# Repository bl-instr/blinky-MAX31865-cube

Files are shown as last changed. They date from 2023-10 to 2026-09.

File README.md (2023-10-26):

#    Blinky-MAX31864 Cube # 
The Blinky-MAX31865 cube is a precision 4 terminal resistance measurement device that integrates into a Blinky-Lite control platform. The cubes incorporates two [Adafruit MAX31865 breakout boards](https://www.adafruit.com/product/3648) providing two independent measurment channels with 15 bits of resolution

## Features: ##
- Seamless integration into the open source [Blinky-Lite control platform](https://www.blinky-lite.se/) 
- Wireless connection for data acquistion and control
- Web interface for wireless connection configuration
- Two independent channels
- Eighth order Chebyschev or power series temperature fit via web interface
- 100 mS pulsed measurements for low self heating
- User defined IIR filtering
- User defined measurement rate
- 15 bits of resolution

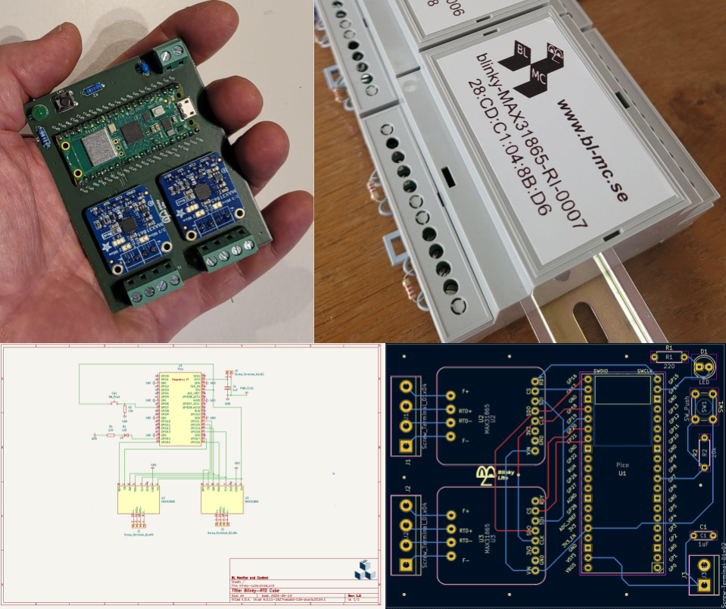
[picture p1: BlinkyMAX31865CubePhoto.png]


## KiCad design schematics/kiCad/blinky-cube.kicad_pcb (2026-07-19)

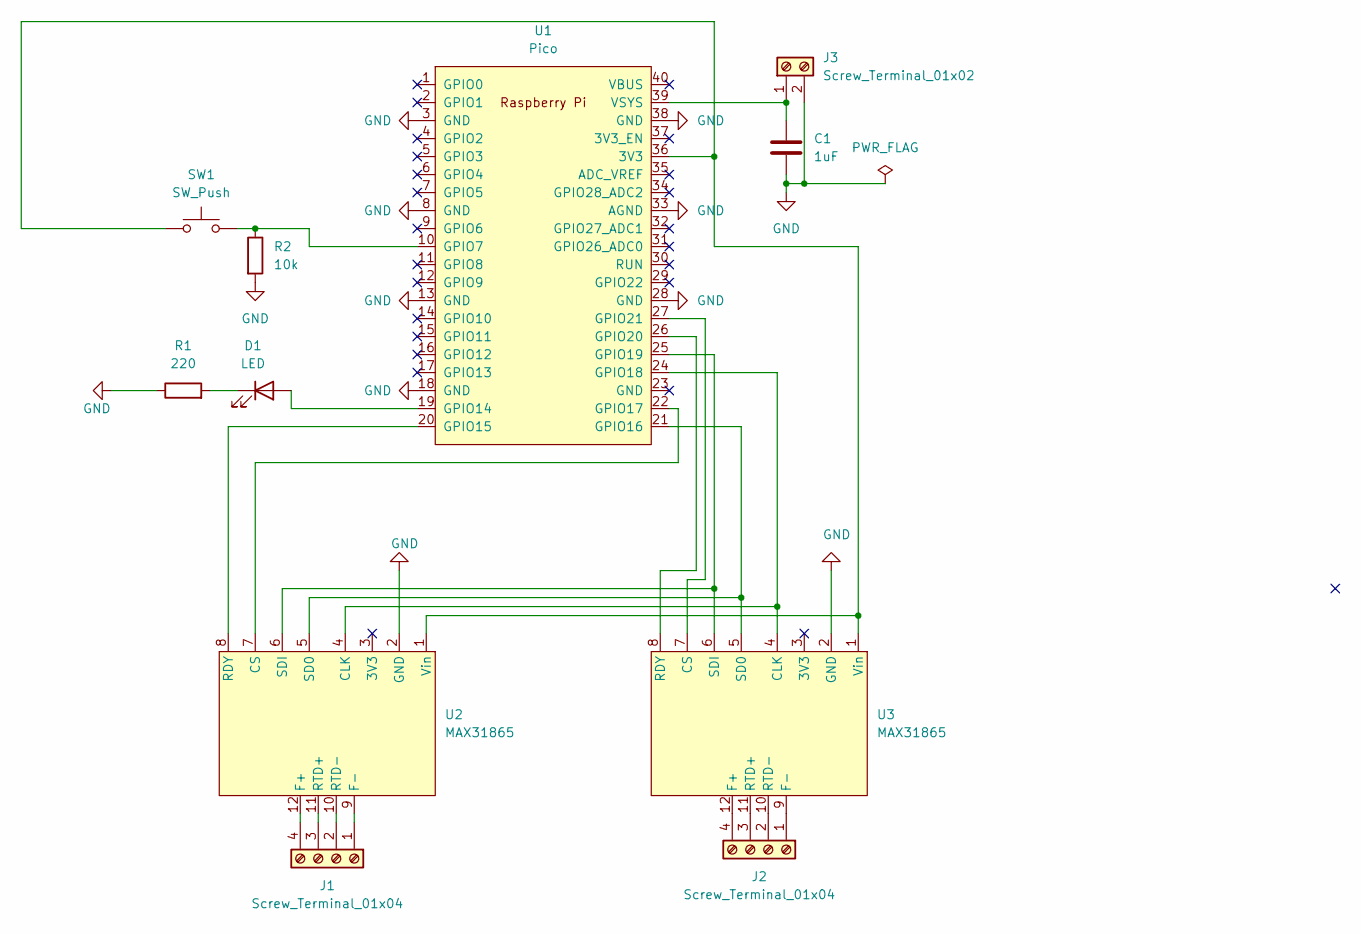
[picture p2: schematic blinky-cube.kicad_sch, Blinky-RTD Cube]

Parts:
C1: 1uF; C_Disc_D4.3mm_W1.9mm_P5.00mm
D1: LED; LED_D5.0mm
J1, J2: Screw_Terminal_01x04; TerminalBlock_bornier-4_P5.08mm
J3: Screw_Terminal_01x02; TerminalBlock_bornier-2_P5.08mm
R1: 220; R_Axial_DIN0207_L6.3mm_D2.5mm_P7.62mm_Horizontal
R2: 10k; R_Axial_DIN0207_L6.3mm_D2.5mm_P7.62mm_Horizontal
SW1: SW_Push; SW_PUSH_6mm
U1: Pico; RPi_Pico_SMD_TH
U2, U3: MAX31865

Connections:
GND: C1.2, J3.2, R1.1, R2.2, U1.3 (GND), U1.8 (GND), U1.13 (GND), U1.18 (GND), U1.28 (GND), U1.33 (AGND), U1.38 (GND), U2.2 (GND), U3.2 (GND)
unnamed: C1.1, J3.1, U1.39 (VSYS)
unnamed: D1.1 (K), R1.2
unnamed: J1.1, U2.9 (F-)
unnamed: J1.2, U2.10 (RTD-)
unnamed: J1.3, U2.11 (RTD+)
unnamed: J1.4, U2.12 (F+)
unnamed: J2.1, U3.9 (F-)
unnamed: J2.2, U3.10 (RTD-)
unnamed: J2.3, U3.11 (RTD+)
unnamed: J2.4, U3.12 (F+)
unnamed: R2.1, SW1.2, U1.10 (GPIO7)
unnamed: SW1.1, U1.36 (3V3), U2.1 (Vin), U3.1 (Vin)
unnamed: D1.2 (A), U1.19 (GPIO14)
unnamed: U1.21 (GPIO16), U2.5 (SD0), U3.5 (SD0)
unnamed: U1.22 (GPIO17), U2.7 (CS)
unnamed: U1.24 (GPIO18), U2.4 (CLK), U3.4 (CLK)
unnamed: U1.25 (GPIO19), U2.6 (SDI), U3.6 (SDI)
unnamed: U1.20 (GPIO15), U2.8 (RDY)
unnamed: U1.27 (GPIO21), U3.7 (CS)
unnamed: U1.26 (GPIO20), U3.8 (RDY)

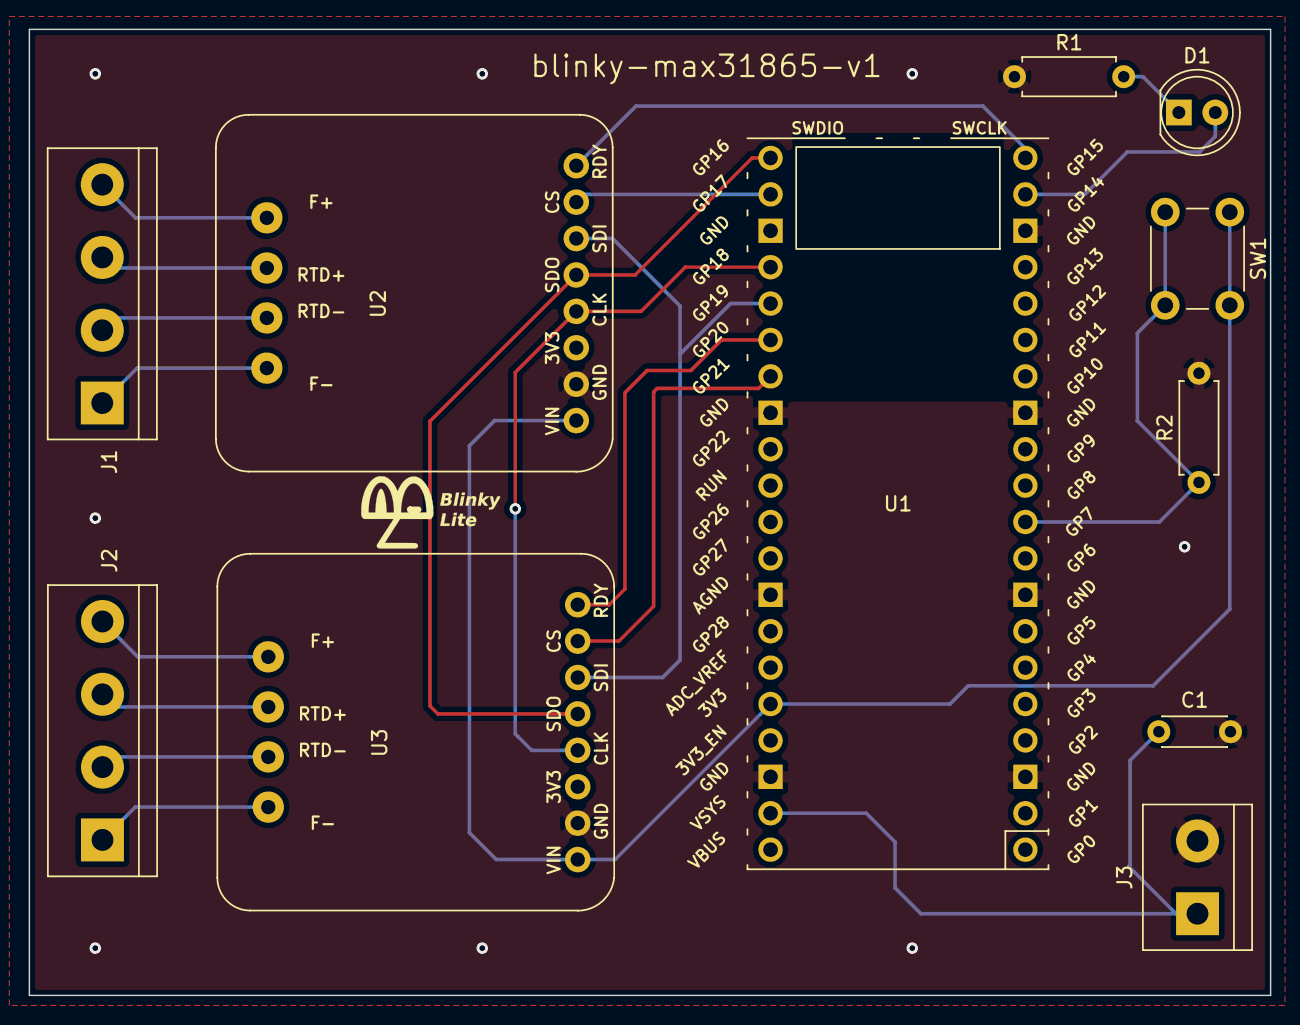
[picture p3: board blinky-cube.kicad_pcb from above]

Board: 2 copper layers, 86.6 x 67.4 mm, 11 parts (0 on the bottom side), 21 nets.

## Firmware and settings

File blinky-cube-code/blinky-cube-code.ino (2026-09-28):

#include <BlinkyPicoW.h>
#include <SPI.h>

// --- Configuration Constants ---
constexpr int BLINKY_DIAG    = 0;
constexpr int CUBE_DIAG      = 0;
constexpr int COMM_LED_PIN   = 14;
constexpr int RST_BUTTON_PIN = 7;
constexpr int NUMCHAN        = 2;

constexpr int CS_PINS[NUMCHAN] = {17, 21};
constexpr int RDY_PINS[NUMCHAN] = {15, 20};
constexpr int POLYSIZE        = 7;

struct CubeSetting
{
  uint16_t nsample;
  uint16_t publishInterval;
  uint16_t measInterval;

/* 
 *  fitType = 0  lin   T, lin   R
 *  fitType = 1  lin   T, log10 R
 *  fitType = 2  log10 T, lin   R
 *  fitType = 3  log10 T, log10 R  
 */
  uint8_t fitType[NUMCHAN];

  float refRes[NUMCHAN];
  float resScale[NUMCHAN];
  float tempScale[NUMCHAN];
  float coef[NUMCHAN][POLYSIZE];
};

struct CubeReading
{
  float res[NUMCHAN];
  float temp[NUMCHAN];
};

struct CubeArm {
  bool res[NUMCHAN];
  bool temp[NUMCHAN];
};

// --- Global Variables ---
CubeSetting setting;
CubeReading reading;
CubeReading readingLow;
CubeReading readingHigh;
CubeArm readingArm;


unsigned long lastMeasureTime;
unsigned long lastPublishTime;
float nsample = 1.0;
uint16_t oldNsample;
uint16_t oldMeasInterval;

SPISettings spiSetting(4000000, MSBFIRST, SPI_MODE3);

// --- Helper Functions ---
template <typename T>
inline bool outsideLimits(T current, T low, T high) {
  return (current < low) || (current > high);
}

void intSpi(int cspin)
{
  SPI.setCS(cspin);
  SPI.beginTransaction(spiSetting);
  changeCsPin(cspin, 0);
  SPI.transfer(0x80);
  SPI.transfer(0x03);
  changeCsPin(cspin, 0);
  SPI.endTransaction();
}

void changeCsPin(int cspin, int val)
{
//  delayMicroseconds(10);
  digitalWrite(cspin, val);
//  delayMicroseconds(10);
}
float readSpi(int cspin)
{
  SPI.setCS(cspin);
  byte spiReadBuffer[4];
  int len = 4;
  for (int ii = 0; ii < len; ++ii) spiReadBuffer[ii] = 0x00;
  
  SPI.beginTransaction(spiSetting);
  changeCsPin(cspin, 0);
  SPI.transfer(0x80);
  SPI.transfer(0x83);
  changeCsPin(cspin, 1);
  SPI.endTransaction();
  
  delay(100);
  
  SPI.beginTransaction(spiSetting);
  changeCsPin(cspin, 0);
  SPI.transfer(0x80);
  SPI.transfer(0xA3);
  changeCsPin(cspin, 1);
  SPI.endTransaction();
  
  SPI.beginTransaction(spiSetting);
  changeCsPin(cspin, 0);
  SPI.transfer(spiReadBuffer,len);
  changeCsPin(cspin, 1);
  SPI.endTransaction();
  
  SPI.beginTransaction(spiSetting);
  changeCsPin(cspin, 0);
  SPI.transfer(0x80);
  SPI.transfer(0x03);
  changeCsPin(cspin, 1);
  SPI.endTransaction();
/*
  Serial.print(spiReadBuffer[0]);
  Serial.print(",");
  Serial.print(spiReadBuffer[1]);
  Serial.print(",");
  Serial.print(spiReadBuffer[2]);
  Serial.print(",");
  Serial.println(spiReadBuffer[3]);
*/
  uint16_t msb = (int16_t) spiReadBuffer[2];
  uint16_t lsb = (int16_t) spiReadBuffer[3];
  msb = msb * 256;
  uint16_t raw = msb + lsb;
  raw = raw / 2;
  float fresNorm = (float) raw;
  fresNorm = fresNorm / 32768.0;
  return fresNorm;
}

void setupBlinky()
{
  if (BLINKY_DIAG > 0) Serial.begin(9600);

  BlinkyPicoW.setMqttKeepAlive(15);
  BlinkyPicoW.setMqttSocketTimeout(4);
  BlinkyPicoW.setMqttPort(1883);
  BlinkyPicoW.setMqttLedFlashMs(100);
  BlinkyPicoW.setHdwrWatchdogMs(8000);

  BlinkyPicoW.begin(BLINKY_DIAG, COMM_LED_PIN, RST_BUTTON_PIN, true, sizeof(setting), sizeof(reading));
}

void setupCube()
{
  if (CUBE_DIAG > 0)
  {
    Serial.begin(9600);
    delay(5000);
  }
  setting.measInterval = 200;
  oldMeasInterval = setting.measInterval;
  setting.publishInterval = 2000;
  setting.nsample = 1;
  oldNsample = setting.nsample;
  nsample = 1.0;
  
  for (int i = 0; i < NUMCHAN; ++i) 
  {
    setting.fitType[i] = 0;
    setting.refRes[i] = 4302.0;
    setting.resScale[i] = 1000.0;
    setting.tempScale[i] = 293.0;
    setting.coef[i][0] = 1.0;
    readingArm.res[i] = true;
    readingArm.temp[i] = true;
    for (int j = 1; j < POLYSIZE; ++j)
    {
      setting.coef[i][j] = 0.0;
      reading.res[i] = 0.0;
    }
    pinMode(RDY_PINS[i], INPUT_PULLDOWN);
    pinMode(CS_PINS[i], OUTPUT);
    digitalWrite(CS_PINS[i], 1);
  }
    
  SPI.setRX(16);
  SPI.setCS(CS_PINS[0]);
  SPI.setSCK(18);
  SPI.setTX(19);  
  SPI.begin(false);
  SPI.setCS(CS_PINS[1]);
  SPI.begin(false);
  intSpi(CS_PINS[0]);
  intSpi(CS_PINS[1]);
  delay(100);
  
  lastPublishTime = millis();
  lastMeasureTime = millis();

  for (int i = 0; i < NUMCHAN; ++i) reading.res[i] = (setting.refRes[i] * readSpi(CS_PINS[i]));
}

float calcTemp(float res, float resScale, float tempScale, uint8_t fitType, float* coef)
{
  float fresPoly = res / resScale;
  if ( (fitType == 1) || (fitType == 3) ) fresPoly = log10(fresPoly);
  float fxton = 1.0;
  float tempNorm = 0.0;
  for (int ipoly = 0; ipoly < POLYSIZE; ++ipoly)
  {
    tempNorm = tempNorm + coef[ipoly] * fxton;
    fxton = fxton * fresPoly;
  }
  if ( (fitType == 2) || (fitType == 3) )
  {
      tempNorm = pow(10.0, tempNorm);
  }
  tempNorm = tempNorm * tempScale;
  return tempNorm;
}
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

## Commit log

2026-07-17 saved in kicad 10
    [blinky-cube.kicad_pcb, blinky-cube.kicad_sch]
2026-07-17 fixed up kicad library
2026-07-19 added logo
    [blinky-cube.kicad_pcb]
